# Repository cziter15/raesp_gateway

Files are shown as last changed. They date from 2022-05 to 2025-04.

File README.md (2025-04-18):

# Project: RaESP Gateway
[![Build with PlatformIO](https://img.shields.io/badge/build%20with-PlatformIO-orange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)](https://platformio.org/)

Hits-of-Code (https://hitsofcode.com/github/cziter15/raesp_gateway/view?branch=main)


**Ra-02 (SX1278) + ESP12-S (ESP8266) gateway**

## What and why?
A few years ago (2018), when I began designing electronics for fun, I made something like a WiFi-controlled 433 MHz remote for RC power outlets I bought from the store. The first version was a mess because I had no clue how to design a PCB. I just connected all the 'wires' on a two-layer board and flooded everything with ground. It worked, but not as reliably as I hoped. Later, I redesigned the board with a focus on minimizing current loops, but even then, not everything worked as intended. More info [here](https://hackaday.io/project/163833-wifi-to-433-mhz-bridge).

In the end, I decided to switch to the Ra-02 instead of the RFM110W. It's theoretically a much better choice because it's programmable and not just a transmitter, but also a transceiver. This means I can both send and receive messages, without being limited to OOK. It even supports LoRa, FSK, and more!

## Hardware overview


To build my PCB, I kept the component count minimal—just a few capacitors, resistors, an LDO regulator (AMS1117) to step down 5V from USB to 3.3V for the modules, an ESP12-S (ESP8266-based module) as the application brain for WiFi connectivity, and a RA-02 (SX1278-based module) to handle all the RF work.

## Software overview


The software is C++ based and powered by [ksIotFrameworkLib](https://github.com/cziter15/ksIotFrameworkLib). It currently supports MQTT and implements the following protocols:

- Ningbo RF protocol
- Nexa RF protocol

At the moment, it only works in transmitter mode, but it's also possible to implement LoRa functionality in the future.

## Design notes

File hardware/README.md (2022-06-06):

# Hardware design : raesp_gateway

## Schematic


## Renders


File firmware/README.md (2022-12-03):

# Firmware : raesp_gateway

This directory contains example firmware for RaEsp gateway device. At this moment only example one-way bridge is implemented `WiFi -> OOK`, but hardware can be used to build more advanced things.

## Features
- Supports transmit protocol for Nexa remote power outlets.
- Supports transmit protocol for Ningbo remote power outlets.
- Supports DS18B20 for room temperature measurement.
- MQTT connectivity

## Compoonents
- RadioCommander - provides Radio Command interface, this component handles message commands coming from MQTT and then handles them by sending apropriate RF messages to remote controlled power outlets.
- TempSensor - optional temperature sensor support (DS18B20) that can be connected to flash/debug header on PCB. Uses RX pin [CFG_RADIO_LED/GPIO1] as power supply and BT [CFG_STATUS_LED/GPIO0] as communication pin.

## Protocols
- Nexa - Nexa RF OOK protocol implementation.
- Ningbo - Ningbo RF OOK protocol implementation.

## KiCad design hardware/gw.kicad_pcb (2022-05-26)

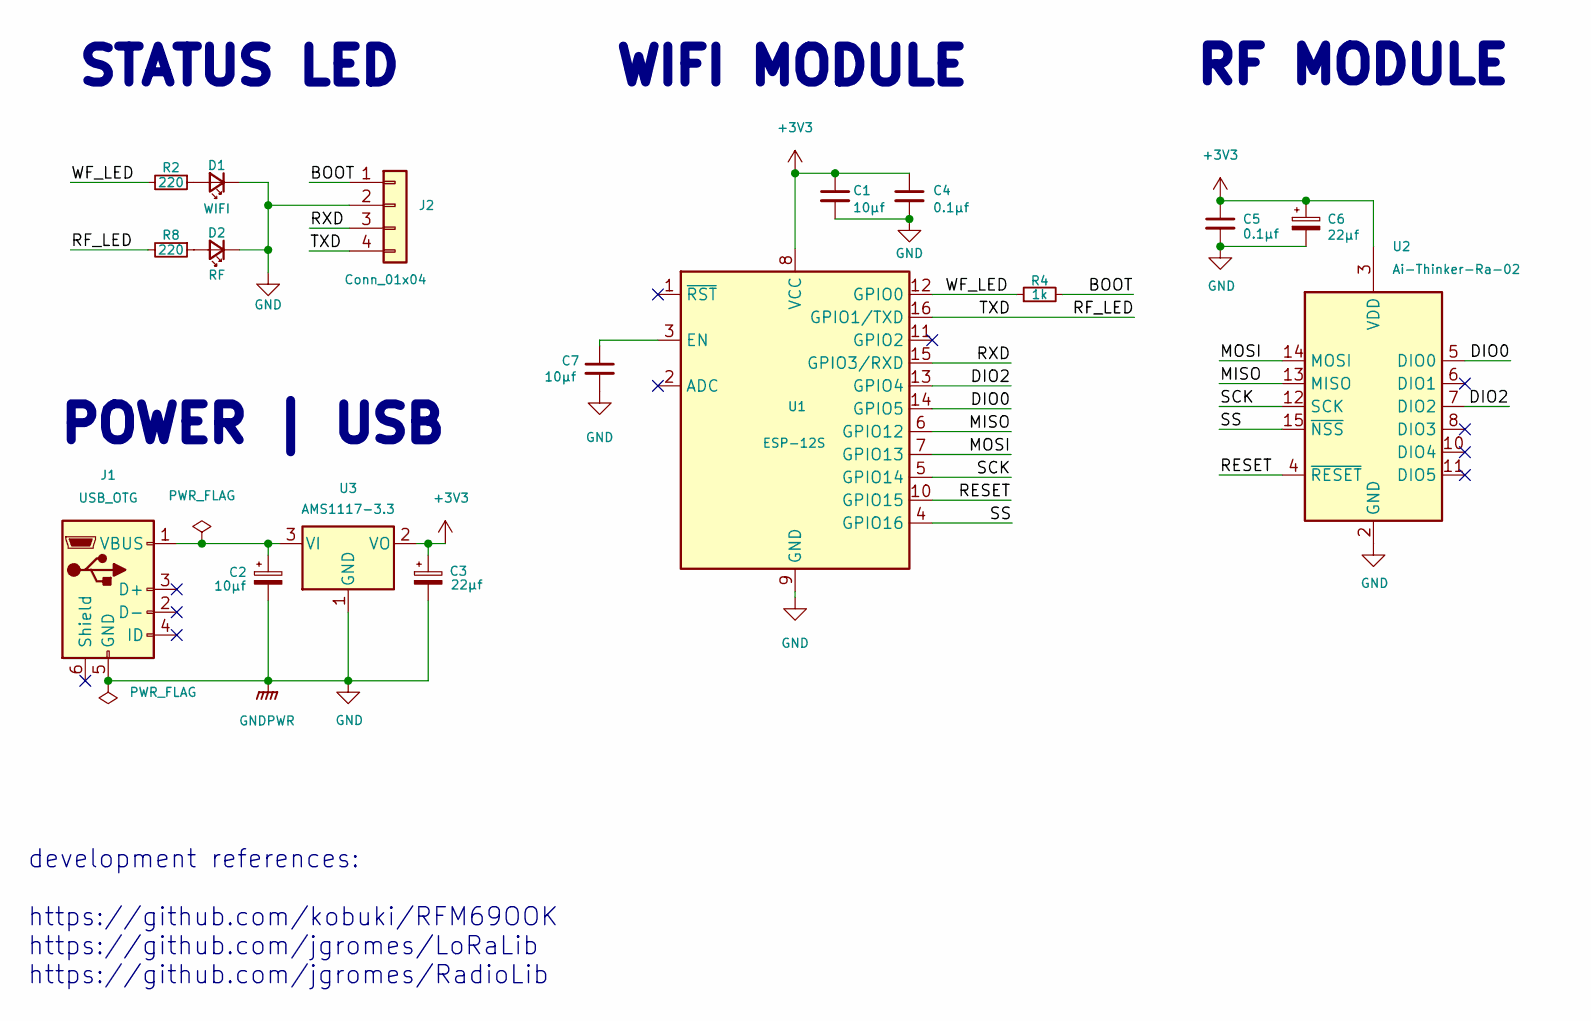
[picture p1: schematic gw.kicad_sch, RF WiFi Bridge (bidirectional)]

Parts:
C1, C7: 10µf; C_1206_3216Metric; LCSC C126946
C2: 10µf; CP_EIA-3216-10_Kemet-I; LCSC C126946
C3, C6: 22µf; CP_EIA-3216-10_Kemet-I; LCSC C126946
C4, C5: 0.1µf; C_1206_3216Metric
D1: WIFI; LED_1206_3216Metric; LCSC C375459
D2: RF; LED_1206_3216Metric; LCSC C375459
J1: USB_OTG; USB_Micro-B_Molex-105017-0001
J2: Conn_01x04; PinHeader_1x04_P2.54mm_Vertical
R2, R8: 220; R_1206_3216Metric; LCSC C17948
R4: 1k; R_1206_3216Metric; LCSC C1489
U1: ESP-12S; ESP-07
U2: Ai-Thinker-Ra-02; Ai-Thinker-Ra-01-LoRa
U3: AMS1117-3.3; SOT-223-3_TabPin2; LCSC C6186

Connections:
+3V3: C1.1, C3.1, C4.1, C5.1, C6.1, U1.8 (VCC), U2.3 (VDD), U3.2 (VO)
/BOOT: J2.1, R4.2
/DIO0: U1.14 (GPIO5), U2.5 (DIO0)
/DIO2: U1.13 (GPIO4), U2.7 (DIO2)
/MISO: U1.6 (GPIO12), U2.13 (MISO)
/MOSI: U1.7 (GPIO13), U2.14 (MOSI)
/RESET: U1.10 (GPIO15), U2.4 (~RESET)
/RF_LED: J2.4, R8.2, U1.16 (GPIO1/TXD)
/RXD: J2.3, U1.15 (GPIO3/RXD)
/SCK: U1.5 (GPIO14), U2.12 (SCK)
/SS: U1.4 (GPIO16), U2.15 (~NSS)
/WF_LED: R2.2, R4.1, U1.12 (GPIO0)
GND: C1.2, C2.2, C3.2, C4.2, C5.2, C6.2, C7.2, D1.1 (K), D2.1 (K), J1.5 (GND), J2.2, U1.9 (GND), U2.1 (GND), U2.2 (GND), U2.9 (GND), U2.16 (GND), U3.1 (GND)
unnamed: C2.1, J1.1 (VBUS), U3.3 (VI)
unnamed: C7.1, U1.3 (EN)
unnamed: D1.2 (A), R2.1
unnamed: D2.2 (A), R8.1

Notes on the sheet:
RF MODULE
development references: https://github.com/kobuki/RFM69OOK https://github.com/jgromes/LoRaLib https://github.com/jgromes/RadioLib
STATUS LED
WIFI MODULE
POWER | USB

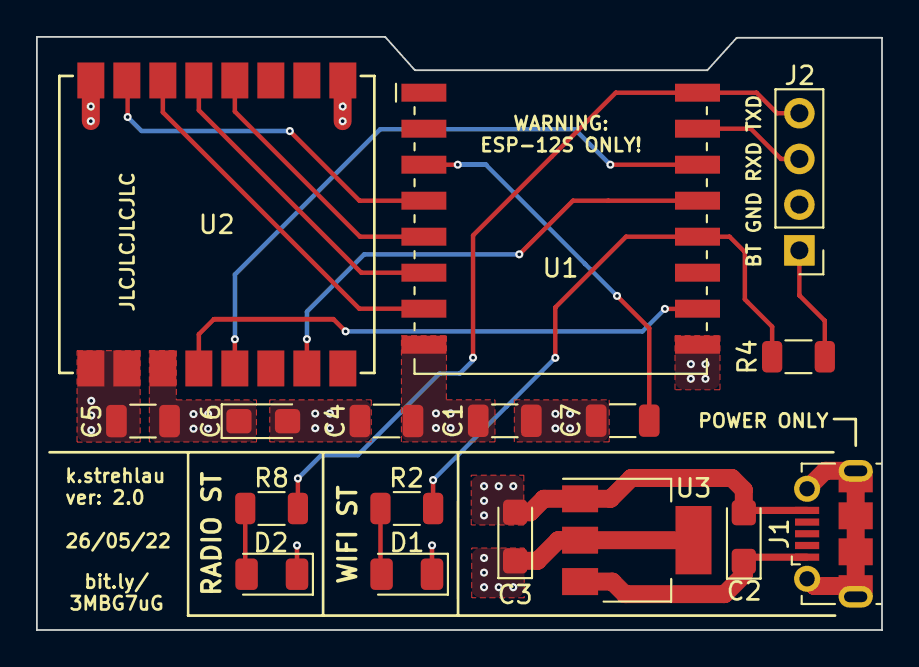
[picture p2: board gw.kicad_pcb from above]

Board: 4 copper layers, 47.0 x 32.9 mm, 17 parts (0 on the bottom side), 17 nets.

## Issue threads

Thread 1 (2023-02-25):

Range enquiry

garudaonekh, 2023-02-25:
Hi,
Interesting idea. Does it have better transmission and receiving range than normal superheterodyne Receiver?  My purpose is to use SX1278 to control normal 433mhz switches and also receive data from RF433 sensors. I used to use CC1101
Thanks

cziter15, 2023-02-25:
To clarify - SX1278 is inside Ra-02. I don't know how it operates versus CC1101. Currently using it to control switches only, so it acts only as a transmitter.

garudaonekh, 2023-02-26:
It look like only transmission exist. How hard it is to add receiving functions?

cziter15, 2023-03-03:
It depends what protocol is used. Packet-mode should be easy.

garudaonekh, 2023-03-03:
ASK mode

garudaonekh, 2023-03-07:
What is the maximum distance you can transmit?

cziter15, 2023-03-14:
ASK is only a modulation mode. You probably have to handle the protocol manually, by handling triggered receive interrupt.
Check RadioLib and other examples for SX1278.

When it comes to distance - it depends. In LoRA mode this might even be kilometers but depends on antenna configuration and the receiver.

cziter15, 2025-01-24:
Closed the issue as the device updates are not planned.

Closed 2025-01-24.

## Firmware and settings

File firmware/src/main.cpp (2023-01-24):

/*
 *	Copyright (c) 2021-2023, Krzysztof Strehlau
 *
 *	This file is part of the RaespDevice (WiFi 433 MHz bridge) firmware.
 *	All licensing information can be found inside LICENSE.md file.
 *
 *	https://github.com/cziter15/raesp_gateway/blob/main/firmware/LICENSE
 */

#include "apps/raesp/RaespDevice.h"
#include "apps/config/RaespDeviceConfig.h"

using namespace apps;

KSF_IMPLEMENT_APP_ROTATOR
(
	raesp::RaespDevice,
	config::RaespDeviceConfig
)

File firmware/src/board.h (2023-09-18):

/*
 *	Copyright (c) 2021-2023, Krzysztof Strehlau
 *
 *	This file is part of the RaespDevice (WiFi 433 MHz bridge) firmware.
 *	All licensing information can be found inside LICENSE.md file.
 *
 *	https://github.com/cziter15/raesp_gateway/blob/main/firmware/LICENSE
 */

#pragma once

/* Pin number used to drive MQTT connection status indicator (LED). */
#define CFG_STATUS_LED 0
/* Pin number used to drive radio activity indicator (LED). */
#define CFG_RADIO_LED 1
/* Pin number used to drive NSS pad of theradio module interface. */
#define CFG_NSS_PIN 16
/* Pin number used to drive DIO0 pad of the radio module interface. */
#define CFG_DIO0_PIN 5
/* Pin number used to drive RST pad of the radio module interface. */
#define CFG_RST_PIN 15
/* Pin number used to drive DIO2 pad of the radio module interface. */
#define CFG_DIO2_PIN 4

/* Transmit power to set on Ra-02 module. */
#define TRANSMIT_POWER_DBM 10
/* Transmit frequency to set on Ra-02 module for NEXA protocol. */
#define TRANSMIT_FREQ_NEXA 433.927
/* Transmit frequency to set on Ra-02 module for NINGBO protocol. */
#define TRANSMIT_FREQ_NINGBO 433.875

#if USE_TEMP_SENSOR
	/* Share temp sensor pins with other functions. */
	#define TEMP_DATA_PIN CFG_STATUS_LED
	/* Share temp sensor pins with other functions. */
	#define TEMP_ENAB_PIN CFG_RADIO_LED
	/* Resolution for measurement. Higher resulution means bigger delay. */
	#define TEMP_SENSOR_RESOLUTION 11
	/* Update interval. Currently five minutes (300000 ms). */
	#define TEMP_UPDATE_INTERVAL_MS 300000UL
#endif

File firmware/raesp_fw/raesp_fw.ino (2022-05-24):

#include "apps/raesp/RaespDevice.h"
#include "apps/config/RaespDeviceConfig.h"

// the setup function runs once when you press reset or power the board
void setup()
{
	ksf::initKsfFramework();
}

// the loop function runs over and over again until power down or reset
void loop()
{
	RUN_APP_BLOCKING_LOOPED(RaespDevice)
	RUN_APP_BLOCKING_LOOPED(RaespDeviceConfig)
}

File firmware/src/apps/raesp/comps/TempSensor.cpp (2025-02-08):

/*
 *	Copyright (c) 2021-2023, Krzysztof Strehlau
 *
 *	This file is part of the RaespDevice (WiFi 433 MHz bridge) firmware.
 *	All licensing information can be found inside LICENSE.md file.
 *
 *	https://github.com/cziter15/raesp_gateway/blob/main/firmware/LICENSE
 */

#include "TempSensor.h"
#include <DS18B20.h>

using namespace std::placeholders;

namespace apps::raesp::comps
{
	#define TEMP_SENSOR_INVALID_TEMP 85.0f

	TempSensor::TempSensor(uint8_t dataPin, uint32_t tempUpdateInterval, std::optional<uint8_t> resolution, std::optional<uint8_t> enabPin)
		: dataPin(dataPin), enabPin(enabPin), resolution(resolution), measurementTimer(tempUpdateInterval)
	{}

	bool TempSensor::init(ksf::ksApplication* app)
	{
		mqttConnWp = app->findComponent<ksf::comps::ksMqttConnector>();
		return true;
	}

	void TempSensor::measureAndPublish(const std::shared_ptr<ksf::comps::ksMqttConnector>& mqttConnSp)
	{
		/* 
			Well this is a bit tricky. Because we are sharing pins with LEDs, we need to cache Direction and LO/HI state.
			Then, when we are done, we should restore pin state and modes so it will look it didn't happen from other components.
		*/
		auto cachedEnabGPC{enabPin.has_value() ? GPC(*enabPin) : 0};	// enabPin ctrl registry.
		auto cachedEnabGPF{enabPin.has_value() ? GPF(*enabPin) : 0};	// enabPin func registry.

		auto cachedDataGPC{GPC(dataPin)};	// dataPin ctrl registry.
		auto cachedDataGPF{GPF(dataPin)};	// dataPin func registry.

		auto cachedGPEC{GPEC};				// GPEC registry.

		/* Cache data pin state. */
		auto cachedEnabState{LOW};
		auto cachedDataState{digitalRead(dataPin)};

		/* Enable power for the sensor. */
		if (enabPin.has_value())
		{
			cachedEnabState = digitalRead(*enabPin);
			pinMode(*enabPin, OUTPUT);
			digitalWrite(*enabPin, HIGH);
		}

		/* Create DS18 handler. */
		if (!ds18handler)
		{
			ds18handler = std::make_unique<DS18B20>(dataPin);
			if (ds18handler && resolution.has_value()) 
				ds18handler->setResolution(*resolution);
		}

		/* Handle temperature measurement. */
		if (ds18handler && ds18handler->getNumberOfDevices() > 0)
		{
			auto tempC{ds18handler->getTempC()};
			if (fabsf(TEMP_SENSOR_INVALID_TEMP - tempC) > std::numeric_limits<float>::epsilon())
				mqttConnSp->publish(PSTR("tempSensor"), ksf::to_string(tempC, 1));
		}
		else
		{
			/* Queue ourselves for removal. */
			componentState = ksf::ksComponentState::ToRemove;
		}

		/* Disable power for the sensor. */
		if (enabPin.has_value())
			digitalWrite(*enabPin, cachedEnabState);

		/* Restore data pin state. */
		pinMode(dataPin, OUTPUT);
		digitalWrite(dataPin, cachedDataState);

		/* Restore saved pin configuration (pin mode). */
		if (enabPin.has_value())
		{
			GPC(*enabPin) = cachedEnabGPC;	// enabPin ctrl registry.
			GPF(*enabPin) = cachedEnabGPF;	// enabPin func registry.
		}

		GPC(dataPin) = cachedDataGPC;	// dataPin ctrl registry.
		GPF(dataPin) = cachedDataGPF;	// dataPin func registry.

		GPEC = cachedGPEC;				// GPEC registry.
	}

	bool TempSensor::loop(ksf::ksApplication* app)
	{
		if (measurementTimer.triggered())
			if (auto mqttConnSp{mqttConnWp.lock()})
				measureAndPublish(mqttConnSp);

		return true;
	}

	TempSensor::~TempSensor() = default;
}

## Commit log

2022-04-27 Change placement of PU resistors
    [gw.kicad_pcb]
2022-04-27 Add leds, fix layout
    [gw.kicad_pcb, gw.kicad_sch]
2022-04-27 Update schematics, almost fab ready
    [gw.kicad_pcb, gw.kicad_sch]
2022-04-27 Add DIO1 pin support
    [gw.kicad_pcb, gw.kicad_sch]
2022-04-27 Fix connector
    [gw.kicad_pcb]
2022-04-27 Fix errors
    [gw.kicad_pcb, gw.kicad_sch]
2022-04-27 Fix hole sizes
    [gw.kicad_pcb]
2022-04-27 Latest fixes
    [gw.kicad_pcb, gw.kicad_sch]
2022-04-27 Fixup pins
    [gw.kicad_pcb, gw.kicad_sch]
2022-04-28 Cleanup sch
    [gw.kicad_sch]
2022-04-28 Latest prefab
    [gw.kicad_pcb, gw.kicad_sch]
2022-04-28 Name changes
    [gw.kicad_pcb, gw.kicad_sch]
2022-04-28 Fix rev
    [gw.kicad_pcb]
2022-04-28 Fix desc
    [gw.kicad_pcb]
2022-05-19 Change resistor value
    [gw.kicad_pcb, gw.kicad_sch]
2022-05-25 Revert "Fixes", move to ESP12F
    This reverts commit ad443d04f57b2ab128a4687db847c72f3a41be2c.
    [gw.kicad_pcb, gw.kicad_sch]
2022-05-26 Revert "Revert "Fixes", move to ESP12F", sticking to ESP12S now.
    This reverts commit af2652227ade2a41ecb2737fc58930674a5f1724.
    [gw.kicad_pcb, gw.kicad_sch]
2022-05-26 Correct version in schematic
    [gw.kicad_sch]
2022-06-14 Fix repeats to be proper as earlier.
    [RadioCommand.cpp]
2022-06-14 Fix wifi / radio led conflict
2022-06-14 No need to hold radioled ptr in device
2022-06-14 Update board image
2022-07-09 Bump output power to 15 dBm
2022-07-10 Set 12 dBm power to PA
2022-07-11 Switch to NonOS SDK v2.2.x 191122
2022-07-14 Remove global ArduinoOTA
2022-08-02 Remove interrupt disabling
2022-08-02 Get back to default ArduinoESP SDK
2022-09-11 Lower TX power
2022-11-01 Add temp sensor support
2022-11-02 Skip sending invalid temp.
    [TempSensor.cpp]
2022-11-02 Fix bug with TempSensor
    [TempSensor.cpp]
2022-11-13 Tweak temp sensor
2022-11-19 Fix project to work with latest ksIotFramework name changes.
    [TempSensor.cpp]
2022-12-03 Change pin name
2022-12-08 Fix temp sensor
2022-12-19 Fix gateway code to be in sync with ksIotFrameworkLib
    [TempSensor.cpp]
2023-01-03 Correct power, add TX drive via PULLUP
    [board.h]
2023-04-13 Fix sensor name
2023-07-08 Fix led pin
2023-09-22 Add device portal
2023-09-25 Revert LED
2023-12-17 Auto-adjust power
2025-10-09 Optimize TempSensor: skip measurement if MQTT disconnected or LED pin is HIGH, use GPIO registers
2025-10-09 Track MQTT connection state to skip measurements when disconnected
2025-10-09 Add thread safety and pin direction check for robustness
2025-10-09 Refactor GPIO handling for temperature sensor
